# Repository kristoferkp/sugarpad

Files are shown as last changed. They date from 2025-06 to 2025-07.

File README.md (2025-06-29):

# sugarpad

A versatile macropad powered by the RP2040 (Seeed Studio Xiao RP2040)

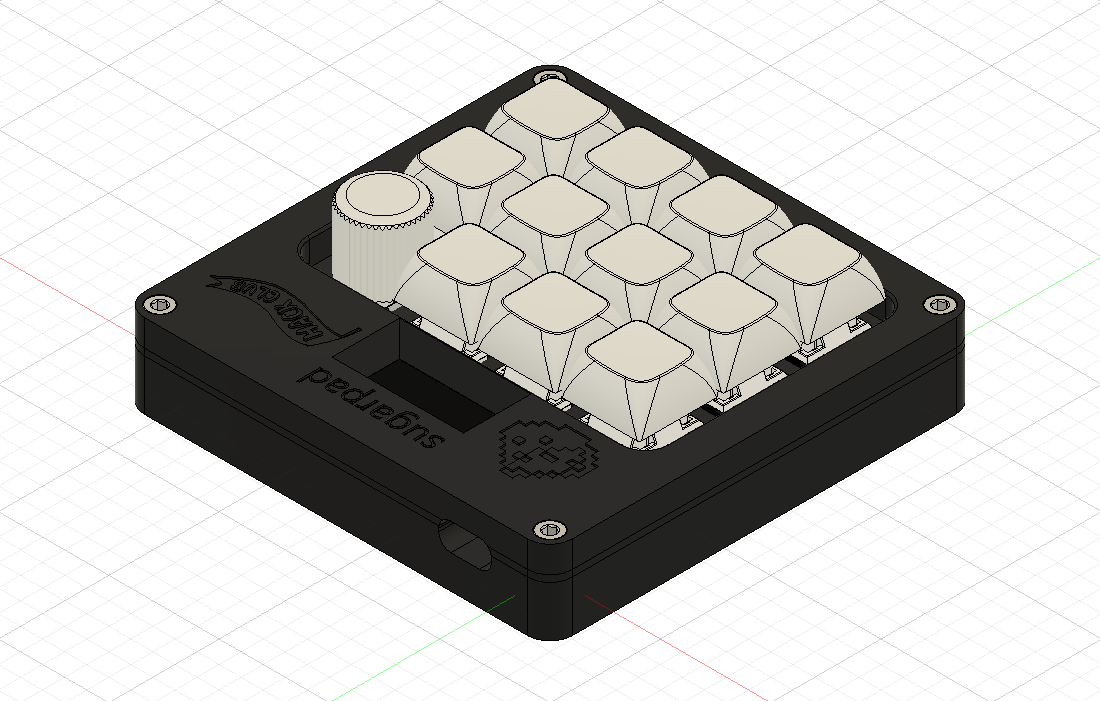
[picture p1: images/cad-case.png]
complete

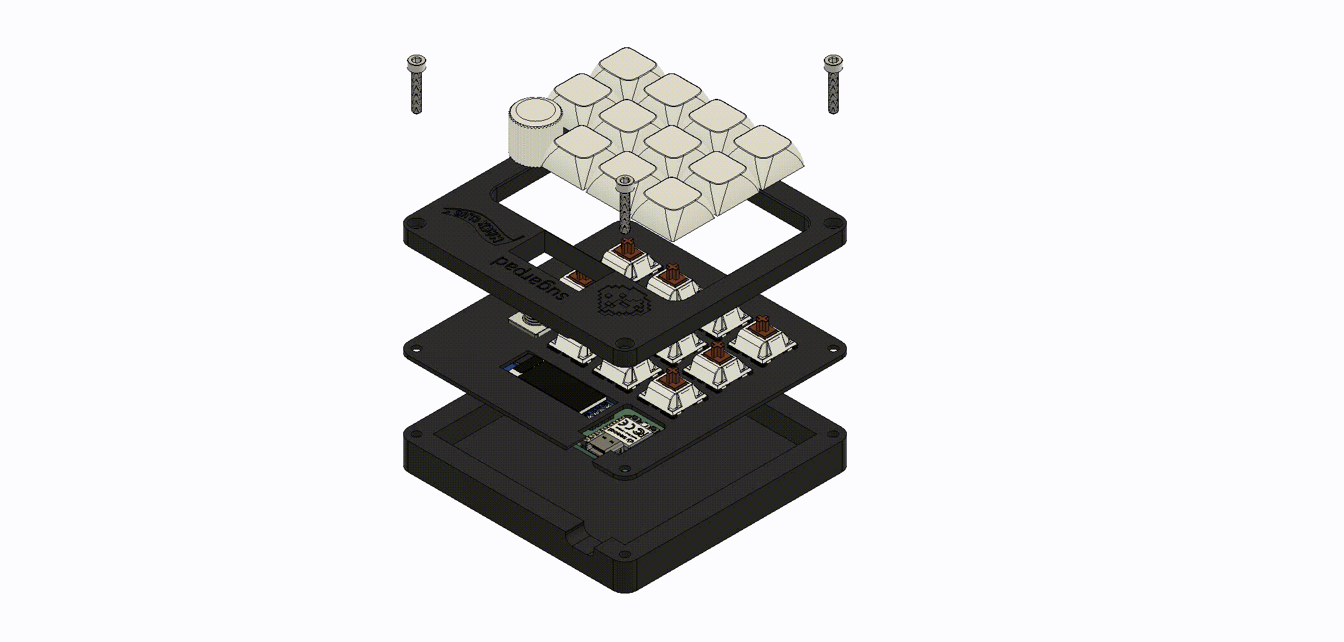
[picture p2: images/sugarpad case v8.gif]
gif


The sugarpad is powered by QMK (with VIA support).
sugarpad is a 11-key macropad with a rotary encoder (with built in switch) and an OLED screen.

The sugarpad is part of Hackclub's [Hackpad project](https://hackpad.hackclub.com/)!

## Firmware
With VIA, you can easily switch out the keymap of the macropad and record macros.

By default the 1st layer is a numpad, the rotary encoder play/pauses music and changes volume.
The keys under the encoder switch layers.

There are a total of 4 layers. 2nd and 3rd layers are F0-F21 and the final layer is unmapped.

By default the OLED screen shows the layer you are on.

## PCB
The PCB was built with KiCad.

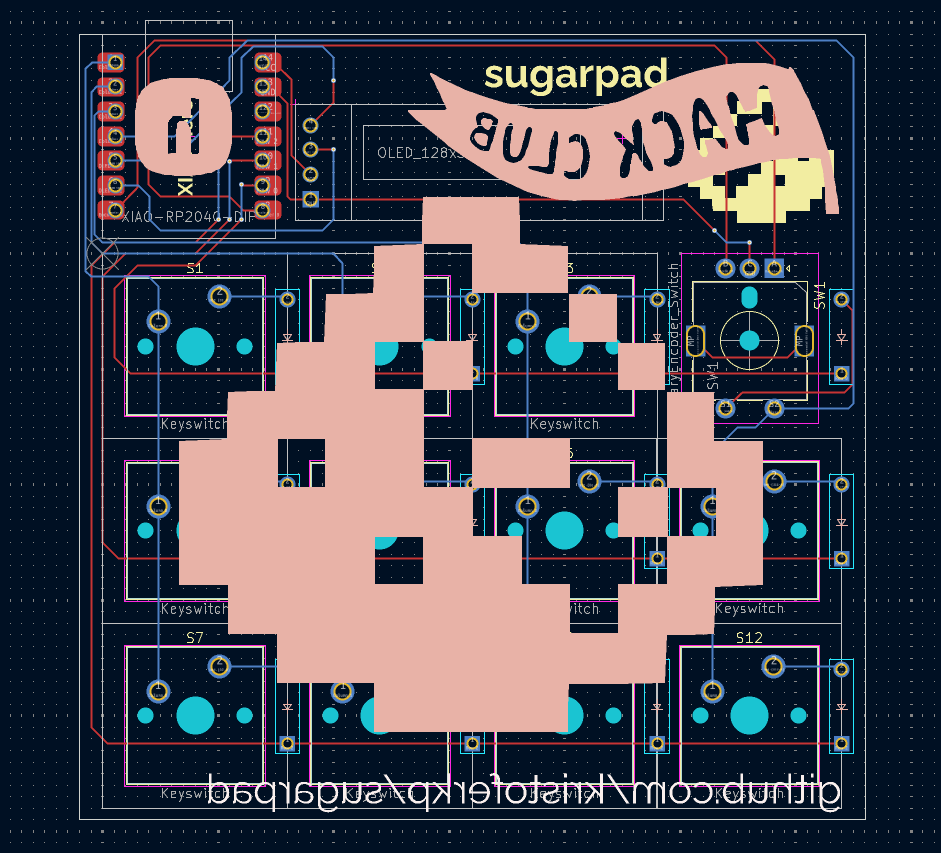
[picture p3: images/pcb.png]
pcb

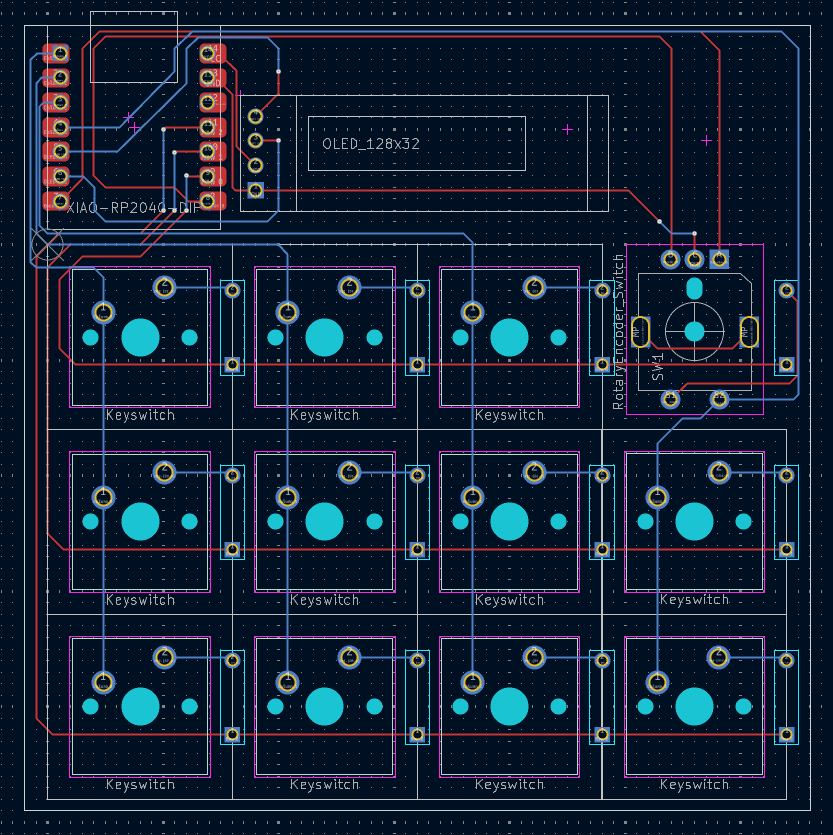
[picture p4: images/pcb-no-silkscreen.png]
pcb-no-silkscreen

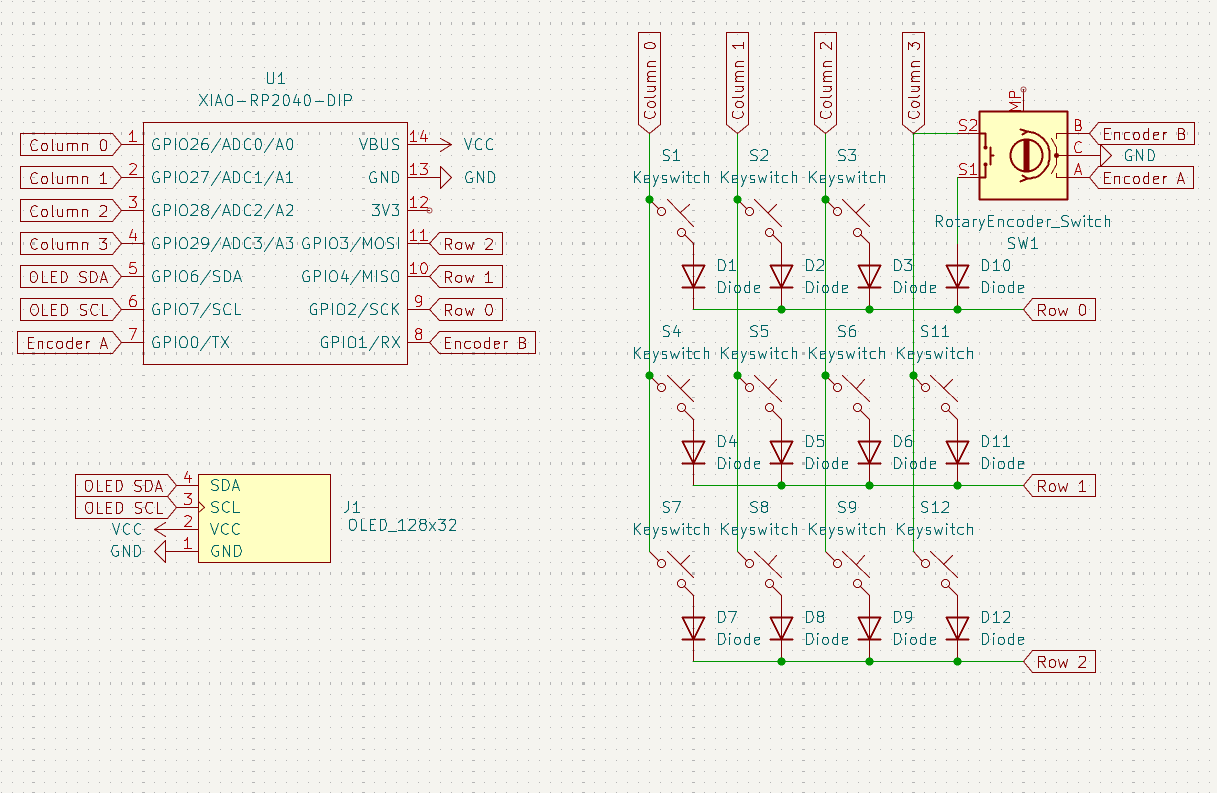
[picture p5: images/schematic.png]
schematic

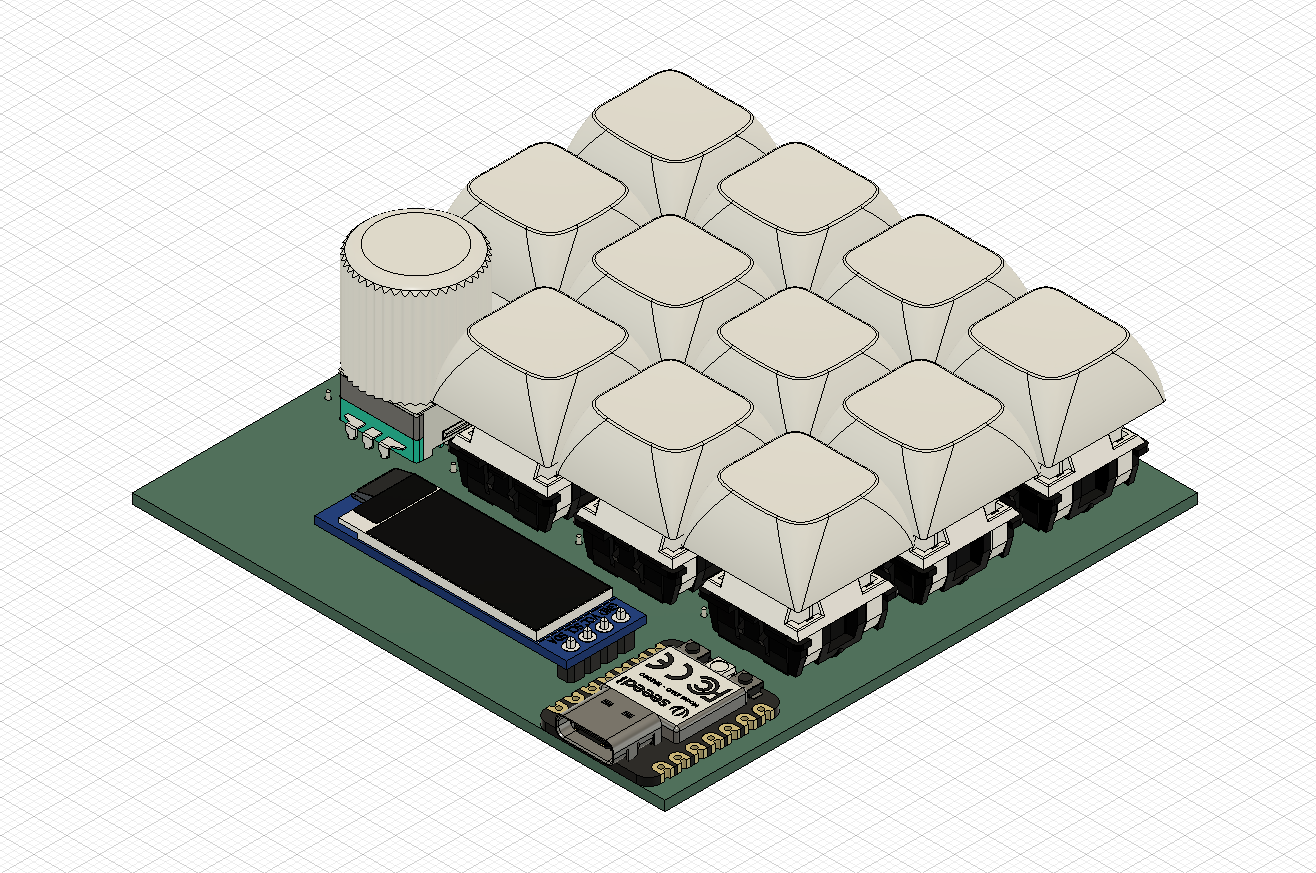
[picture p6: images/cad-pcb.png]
pcb-step


## Case
The case can be printed in 3 parts - the bottom, the plate and the top. 
The case uses 4 M3x16 screws and 4 M3x5x4mm heatset inserts.

case
gif
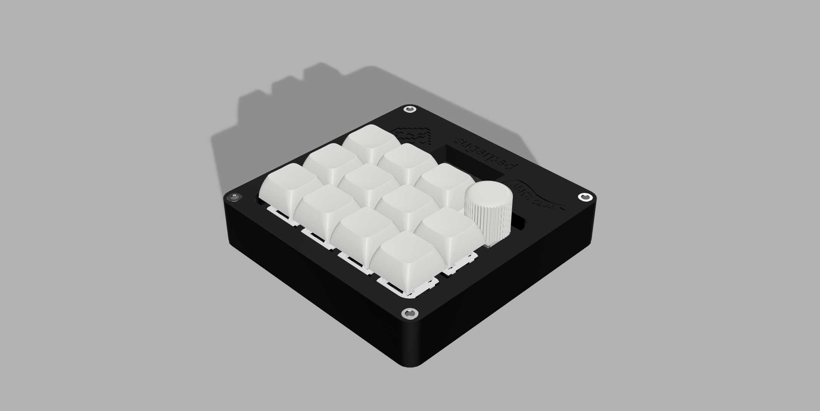
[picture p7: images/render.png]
render


Small amount of supports are required (USB-C hole, heatset insert holes)

## BOM
- 1x Seeed Studio Xiao RP2040
- 1x EC11E Rotary Encoder (switch built in)
- 1x rotary Encoder Knob (can also be printed)
- 1x 0.91" SSD1306 OLED screen
- 11x Cherry MX style switches
- 11x Blank DSA keycaps
- 12x DO-35 diodes (THT)

## Case
- 4x M3x16mm socket head bolts
- 4x M3x5x4mm heatset inserts
- 1x top_case.step
- 1x plate.step
- 1x bottom_case.step

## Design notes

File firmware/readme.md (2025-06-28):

# sugarpad

My first macropad and first PCB designed. Made for the Hackclub's [Hackpad project](https://hackpad.hackclub.com/).

* Keyboard Maintainer: [Kristofer P](https://github.com/kristoferkp)
* Hardware Supported: RP2040 (Seeed studio XIAO RP2040)
* Hardware Availability: Nowhere ;)

QMK compile command:
´´´bash
qmk compile -kb sugarpad -km default
´´´

See the [build environment setup](https://docs.qmk.fm/#/getting_started_build_tools) and the [make instructions](https://docs.qmk.fm/#/getting_started_make_guide) for more information. Brand new to QMK? Start with our [Complete Newbs Guide](https://docs.qmk.fm/#/newbs).

## Bootloader

Enter the bootloader in 3 ways:

* **Bootmagic reset**: Hold down the key at (0,0) in the matrix (usually the top left key or Escape) and plug in the keyboard
* **Physical reset button**: Briefly press the button on the XIAO RP2040
* **Keycode in layout**: Press the key mapped to `QK_BOOT` if it is available

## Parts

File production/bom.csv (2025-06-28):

Designator | Footprint | Quantity | Value | LCSC Part #
D1, D10, D11, D12, D2, D3, D4, D5, D6, D7, D8, D9 | Diode_DO-35 | 12 | Diode
J1 | OLED_128x32 | 1 | OLED_128x32
S1, S11, S12, S2, S3, S4, S5, S6, S7, S8, S9 | MX_PCB_1.00u | 11 | Keyswitch
SW1 | RotaryEncoder_Alps_EC11E-Switch_Vertical_H20mm_MountingHoles | 1 | RotaryEncoder_Switch
U1 | Seeed_XIAO_RP2040 | 1 | XIAO-RP2040-DIP

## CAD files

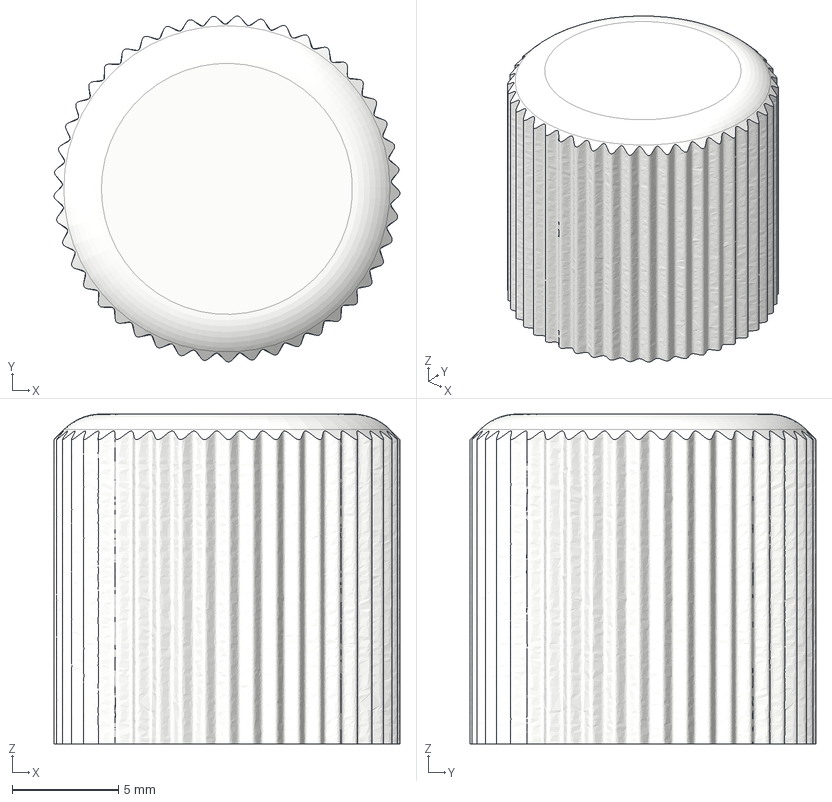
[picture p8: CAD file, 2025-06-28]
cad/knob.step
16.3 x 16.2 x 15.5 mm

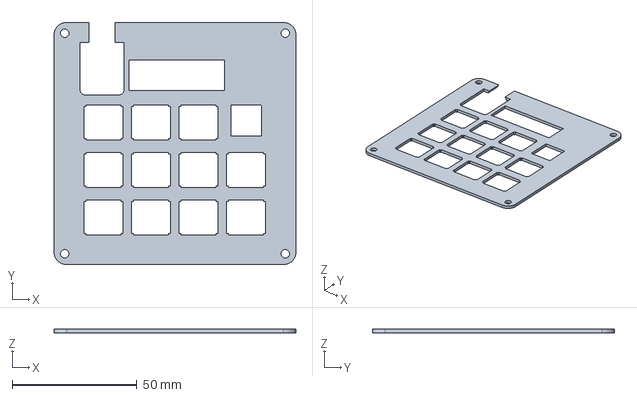
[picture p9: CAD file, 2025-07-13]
production/Plate.step
97.0 x 97.0 x 1.50 mm

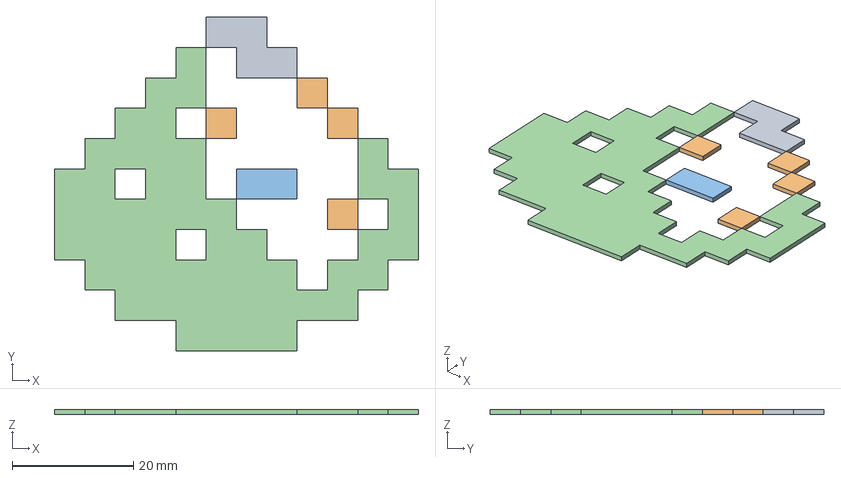
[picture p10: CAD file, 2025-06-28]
cad/decal.step
60.0 x 55.0 x 0.8 mm

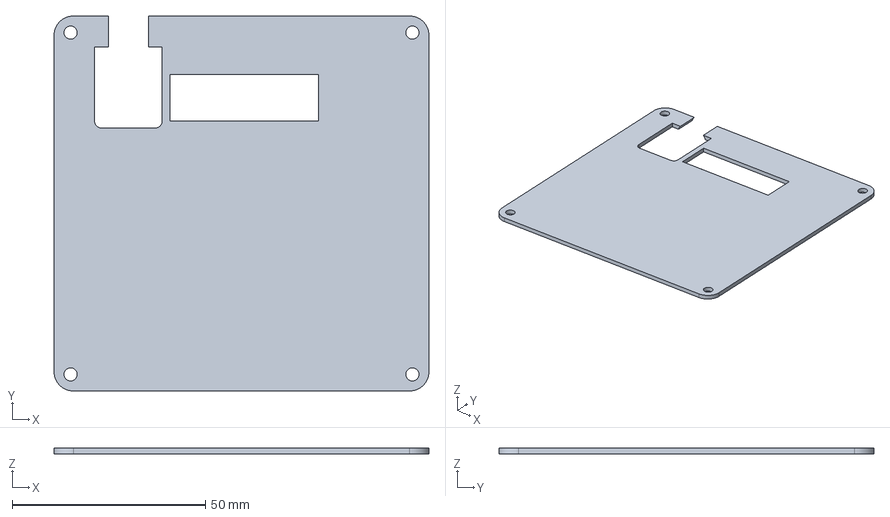
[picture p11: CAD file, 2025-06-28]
cad/plate.step
97.0 x 97.0 x 1.50 mm

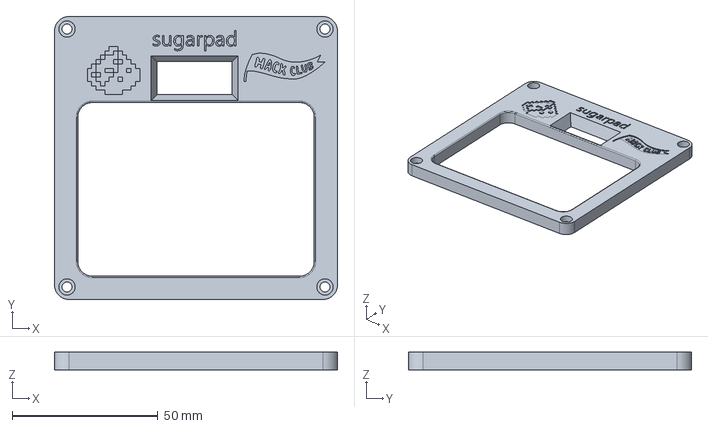
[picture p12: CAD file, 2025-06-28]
production/top_case.step
97.0 x 97.0 x 6.00 mm

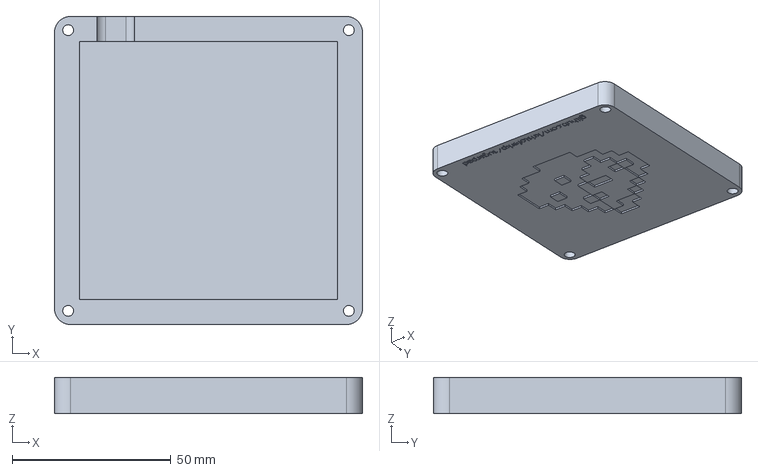
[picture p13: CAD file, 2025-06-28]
production/bottom_case.step
97.0 x 97.0 x 11.5 mm

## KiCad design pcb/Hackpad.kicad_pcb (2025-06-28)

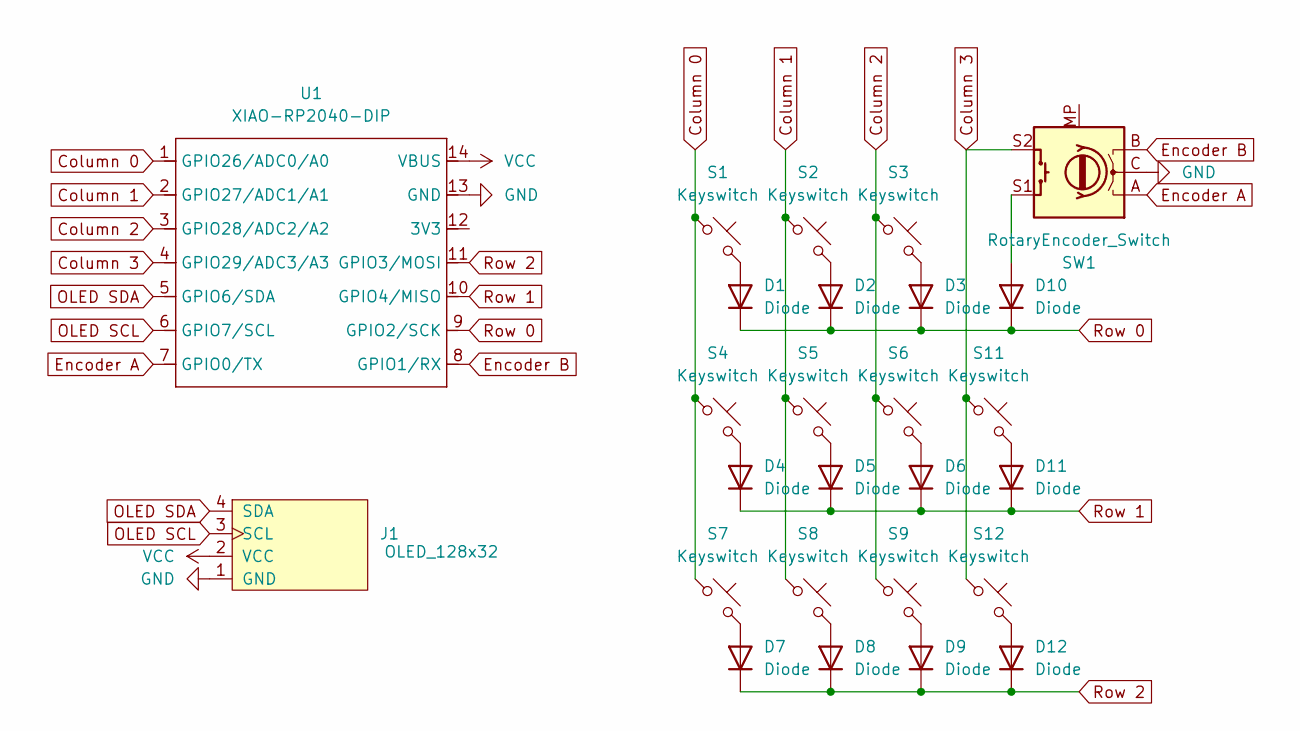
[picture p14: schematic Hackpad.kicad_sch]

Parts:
D1, D2, D3, D4, D5, D6, D7, D8, D9, D10, D11, D12: Diode; Diode_DO-35
J1: OLED_128x32
S1, S2, S3, S4, S5, S6, S7, S8, S9, S11, S12: Keyswitch; MX_PCB_1.00u
SW1: RotaryEncoder_Switch; RotaryEncoder_Alps_EC11E-Switch_Vertical_H20mm_MountingHoles
U1: XIAO-RP2040-DIP; Seeed_XIAO_RP2040

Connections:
Column 0: S1.1, S4.1, S7.1, U1.1 (GPIO26/ADC0/A0)
Column 1: S2.1, S5.1, S8.1, U1.2 (GPIO27/ADC1/A1)
Column 2: S3.1, S6.1, S9.1, U1.3 (GPIO28/ADC2/A2)
Column 3: S11.1, S12.1, SW1.S2, U1.4 (GPIO29/ADC3/A3)
Encoder A: SW1.A, U1.7 (GPIO0/TX)
Encoder B: SW1.B, U1.8 (GPIO1/RX)
GND: J1.1 (GND), SW1.C, U1.13 (GND)
unnamed: D1.2 (A), S1.2
unnamed: D2.2 (A), S2.2
unnamed: D3.2 (A), S3.2
unnamed: D4.2 (A), S4.2
unnamed: D5.2 (A), S5.2
unnamed: D6.2 (A), S6.2
unnamed: D7.2 (A), S7.2
unnamed: D8.2 (A), S8.2
unnamed: D9.2 (A), S9.2
unnamed: D10.2 (A), SW1.S1
unnamed: D11.2 (A), S11.2
unnamed: D12.2 (A), S12.2
OLED SCL: J1.3 (SCL), U1.6 (GPIO7/SCL)
OLED SDA: J1.4 (SDA), U1.5 (GPIO6/SDA)
Row 0: D1.1 (K), D2.1 (K), D3.1 (K), D10.1 (K), U1.9 (GPIO2/SCK)
Row 1: D4.1 (K), D5.1 (K), D6.1 (K), D11.1 (K), U1.10 (GPIO4/MISO)
Row 2: D7.1 (K), D8.1 (K), D9.1 (K), D12.1 (K), U1.11 (GPIO3/MOSI)
VCC: J1.2 (VCC), U1.14 (VBUS)

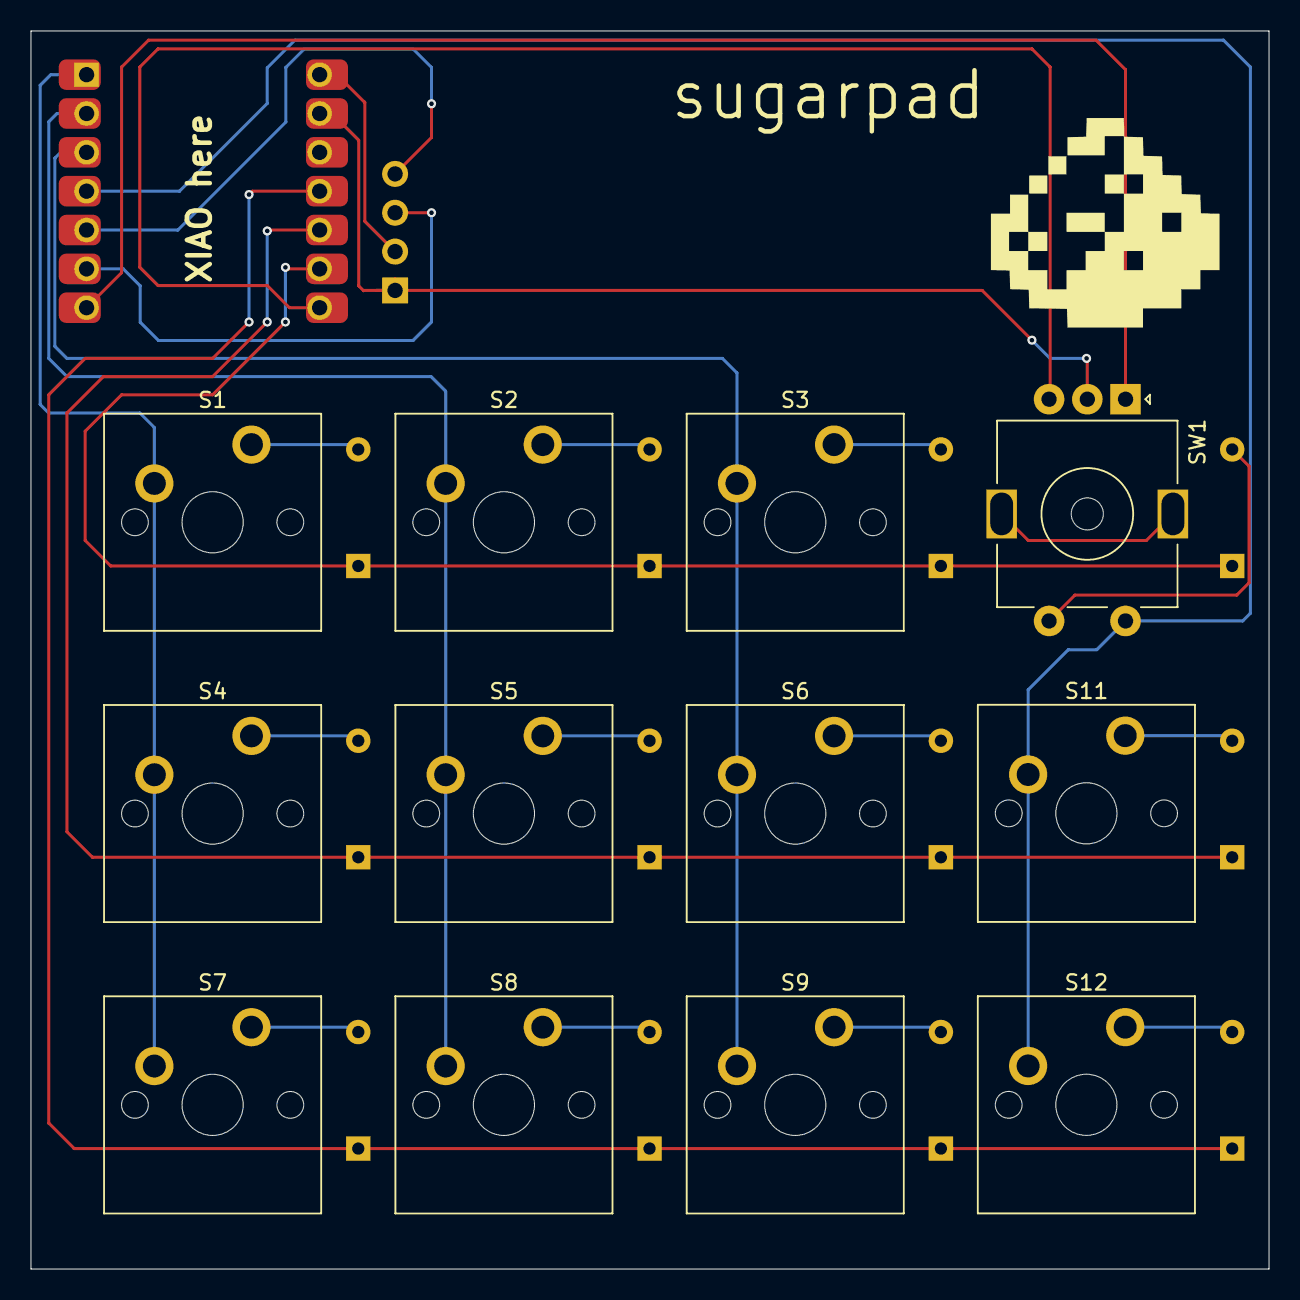
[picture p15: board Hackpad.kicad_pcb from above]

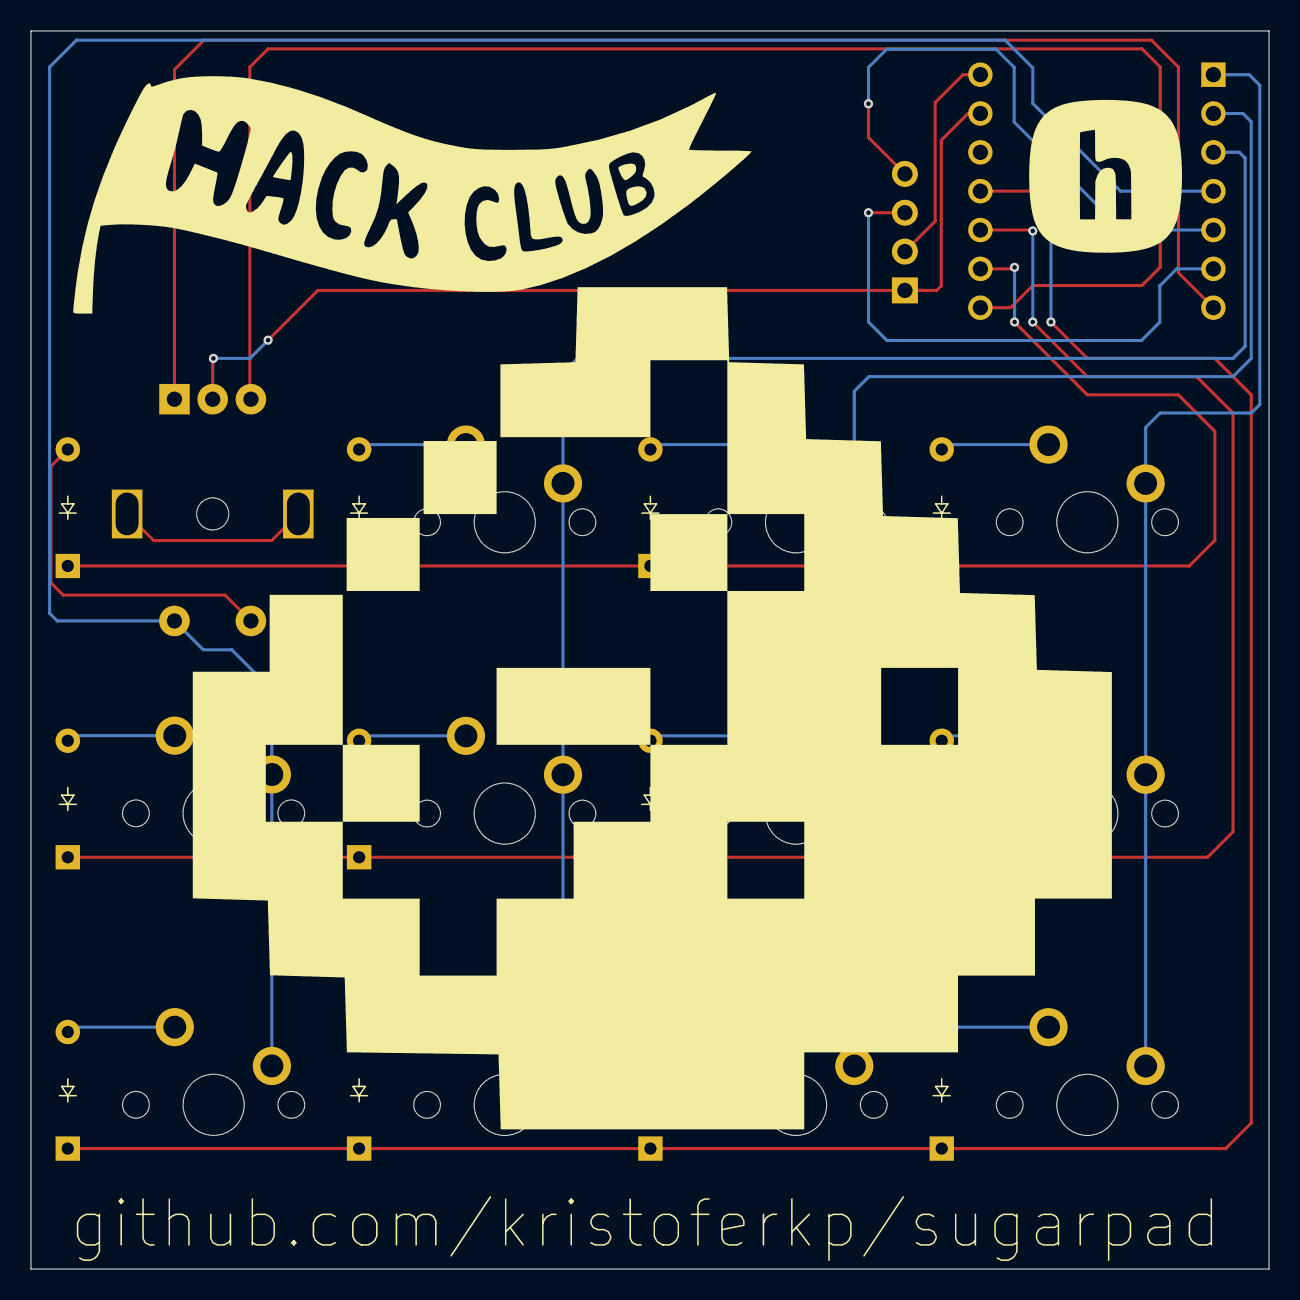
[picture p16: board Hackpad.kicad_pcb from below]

Board: 2 copper layers, 81.0 x 81.0 mm, 26 parts (12 on the bottom side), 25 nets.

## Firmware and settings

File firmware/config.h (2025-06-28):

#define ENCODER_A_PINS {GP0}
#define ENCODER_B_PINS {GP1}
#define NUM_ENCODERS 1
#define I2C_DRIVER I2CD1
#define I2C1_SDA_PIN GP6
#define I2C1_SCL_PIN GP7

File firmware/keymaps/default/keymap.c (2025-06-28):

// Copyright 2023 QMK
// SPDX-License-Identifier: GPL-2.0-or-later

#include QMK_KEYBOARD_H

const uint16_t PROGMEM keymaps[][MATRIX_ROWS][MATRIX_COLS] = {
    [0] = LAYOUT(
        KC_P7,   KC_P8,   KC_P9,   KC_MPLY,
        KC_P4,   KC_P5,   KC_P6,   TO(1),
        KC_P1,   KC_P2,   KC_P3,   TO(3)
    ),
    [1] = LAYOUT(
        KC_F7,   KC_F8,   KC_F9,   KC_MPLY,
        KC_F4,   KC_F5,   KC_F6,   TO(2),
        KC_F1,   KC_F2,   KC_F3,   TO(0)
    ),
    [2] = LAYOUT(
        KC_F13,    KC_F14,    KC_F15,    KC_MPLY,
        KC_F16,    KC_F17,    KC_F18,    TO(3),
        KC_F19,    KC_F20,    KC_F21,    TO(0)
    ),
    [3] = LAYOUT(
        KC_TRNS,    KC_TRNS,    KC_TRNS,    KC_MPLY,
        KC_TRNS,    KC_TRNS,    KC_TRNS,    TO(0),
        KC_TRNS,    KC_TRNS,    KC_TRNS,    TO(1)
    )
};

const uint16_t PROGMEM encoder_map[][1][2] = {
    [0] = {ENCODER_CCW_CW(KC_VOLD, KC_VOLU)},
    [1] = {ENCODER_CCW_CW(KC_VOLD, KC_VOLU)},
    [2] = {ENCODER_CCW_CW(KC_VOLD, KC_VOLU)},
    [3] = {ENCODER_CCW_CW(KC_VOLD, KC_VOLU)},
};

#ifdef OLED_ENABLE
bool oled_task_user(void) {
    // Host Keyboard Layer Status
    oled_write_P(PSTR("Layer: "), false);

    switch (get_highest_layer(layer_state)) {
        case 0:
            oled_write_P(PSTR("Default\n"), false);
            break;
        case 1:
            oled_write_P(PSTR("1\n"), false);
            break;
        case 2:
            oled_write_P(PSTR("2\n"), false);
            break;
        case 3:
            oled_write_P(PSTR("3\n"), false);
            break;
        default:
            // Or use the write_ln shortcut over adding '\n' to the end of your string
            oled_write_ln_P(PSTR("Undefined"), false);
    }

    return false;
}
#endif

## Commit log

2025-06-28 added needed files maybe
    [Hackpad.kicad_pcb, Hackpad.kicad_sch, bom.csv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]
2025-06-28 added step files
    [bottom_case.3mf, bottom_case.step, decal.step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]
2025-06-28 accidentally exported knob as f3d
    [knob.f3d, knob.step]
2025-07-13 fixed plate
    [Plate.step]
2025-07-13 actually fixed the file
    [Plate.step]
